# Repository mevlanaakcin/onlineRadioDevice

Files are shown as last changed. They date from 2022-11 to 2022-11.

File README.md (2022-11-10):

# onlineRadioStreamDevice
Bir IoT projesi olarak internet tabanlı radio yayın akışı oynatma projesi<br>
<h3>PCB Tasarımı</h3><br>
Elektronik devre şeması ve PCB board tasarımı Eagle de tasarlandı.<br>


<h3>Masaüstü Uygulama</h3><br>
C# ile masaüstü uygulaması sayesinde cihazın set ayarları yapılabiliyor. Wifi bilgileri set edilebiliyor. Yayın akışı takip edilecek link bilgileri set edilebiliyor. Cihaza isim atanabiliyor. Tüm bu işlemler masaüstü uygulaması ile cihaz arasında serial haberleşme ile yapılıyor. Cihaza daha önceden set edilen bilgiler çekilebiliyor.<br>

<h3>Gömülü Yazılım</h3><br>
ESP8266 kullanarak Wifi desteğinden faydalanarak gömülü yazılımı geliştirdim.<br>
EEPROM hafıza kullanıldı.<br>
Serial Haberleşme kullanıldı.<br>
WPS Bağlantı kullanıldı.<br>
I2S kullanıldı.<br>

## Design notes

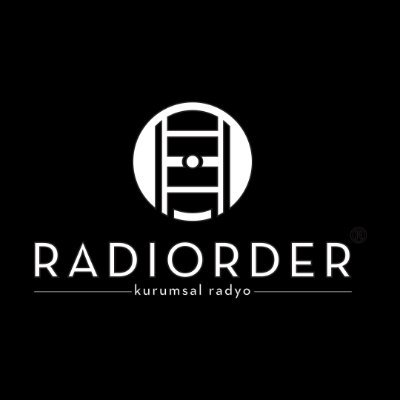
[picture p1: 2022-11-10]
Masaüstü Uygulama/Resources/q3KudRJM.jpg

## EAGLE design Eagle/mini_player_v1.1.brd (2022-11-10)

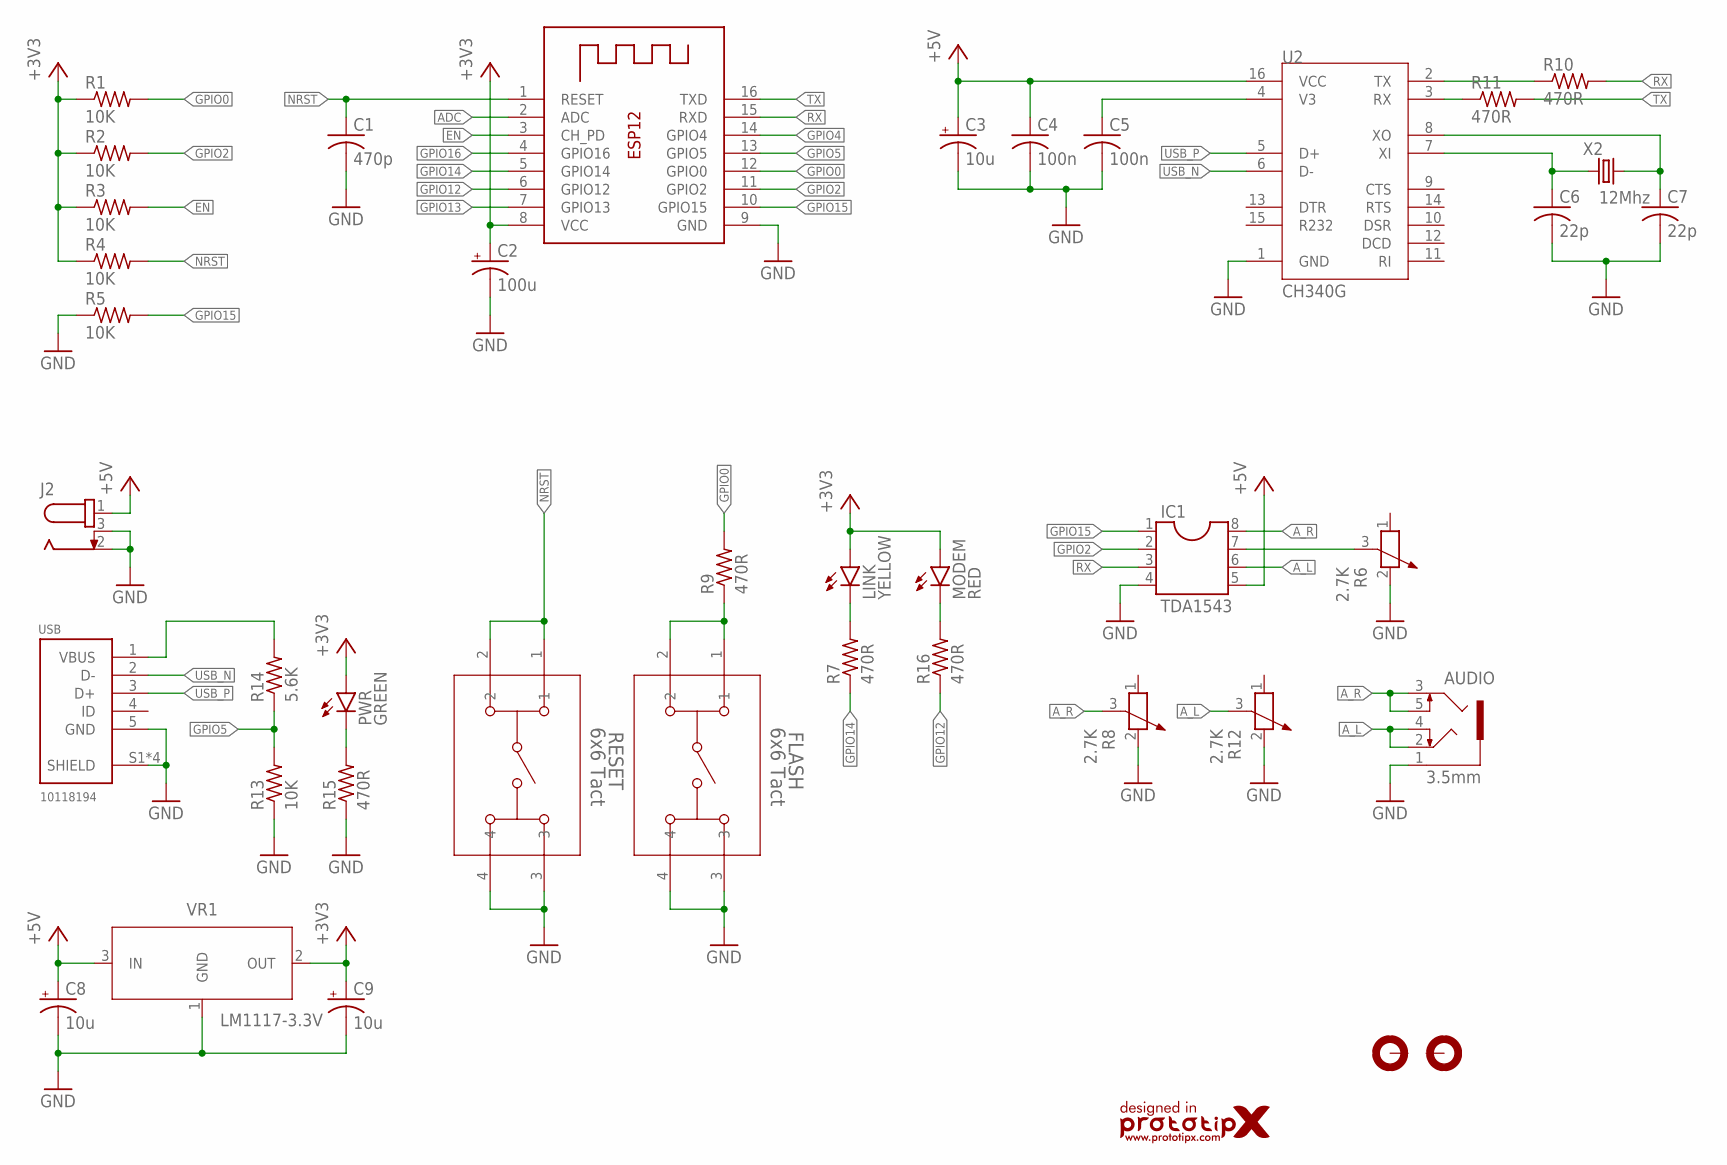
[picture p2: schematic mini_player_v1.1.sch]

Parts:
AUDIO: 3.5mm; 1503_09
C1: 470p; C0805
C2: 100u; SMC_B
C3, C8, C9: 10u; SMC_B
C4, C5: 100n; C0805
C6, C7: 22p; C0805
FLASH: 6x6 Tact; SW4_1825910-G
H1, H2: MOUNT-PAD-ROUND3.6; 3,6-PAD
IC1: TDA1543; DIL08
J2: 694106301002
LINK: YELLOW; LED3MM
LOGO1: PROTOTIPXDESIGN2; PROTOTIPX_DESING_15MM
MODEM: RED; LED3MM
PWR: GREEN; LED3MM
R1, R2, R3, R4, R5, R13: 10K; R0805
R6, R8, R12: 2.7K; PT-10
R7, R9, R10, R11, R15, R16: 470R; R0805
R14: 5.6K; R0805
RESET: 6x6 Tact; SW4_1825910-G
U1: ESP12E; ESP-12
U2: CH340G; SOIC16
USB: 10118194
VR1: LM1117-3.3V; SOT230P700X170-4
X2: 12Mhz; 5032/2P

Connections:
+3V3: C2.+, C9.+, LINK.A, MODEM.A, PWR.A, R1.1, R2.1, R3.1, R4.1, U1.8 (VCC), VR1.2 (OUT)
+5V: C3.+, C4.1, C8.+, IC1.5, J2.1, U2.16 (VCC), VR1.3 (IN)
ADC: U1.2 (ADC)
A_L: AUDIO.2, AUDIO.4, IC1.6, R12.3
A_R: AUDIO.3, AUDIO.5, IC1.8, R8.3
EN: R3.2, U1.3 (CH_PD)
GND: AUDIO.1, C1.2, C2.-, C3.-, C4.2, C5.2, C6.2, C7.2, C8.-, C9.-, FLASH.3, FLASH.4, IC1.4, J2.2, J2.3, R5.1, R6.2, R8.2, R12.2, R13.1, R15.1, RESET.3, RESET.4, U1.9 (GND), U2.1 (GND), USB.5 (GND), USB.S1 (SHIELD), USB.S2 (SHIELD), USB.S3 (SHIELD), USB.S6 (SHIELD), VR1.1 (GND)
GPIO0: R1.2, R9.2, U1.12 (GPIO0)
GPIO2: IC1.2, R2.2, U1.11 (GPIO2)
GPIO4: U1.14 (GPIO4)
GPIO5: R13.2, R14.1, U1.13 (GPIO5)
GPIO12: R16.1, U1.6 (GPIO12)
GPIO13: U1.7 (GPIO13)
GPIO14: R7.1, U1.5 (GPIO14)
GPIO15: IC1.1, R5.2, U1.10 (GPIO15)
GPIO16: U1.4 (GPIO16)
unnamed: R14.2, USB.1 (VBUS)
unnamed: FLASH.1, FLASH.2, R9.1
unnamed: C5.1, U2.4 (V3)
unnamed: C6.1, U2.7 (XI), X2.1
unnamed: C7.1, U2.8 (XO), X2.2
unnamed: R11.1, U2.3 (RX)
unnamed: R10.1, U2.2 (TX)
unnamed: MODEM.K (C), R16.2
unnamed: PWR.K (C), R15.2
unnamed: LINK.K (C), R7.2
NRST: C1.1, R4.2, RESET.1, RESET.2, U1.1 (RESET)
RX: IC1.3, R10.2, U1.15 (RXD)
TX: R11.2, U1.16 (TXD)
USB_N: U2.6 (D-), USB.2 (D-)
USB_P: U2.5 (D+), USB.3 (D+)
VREF: IC1.7, R6.3

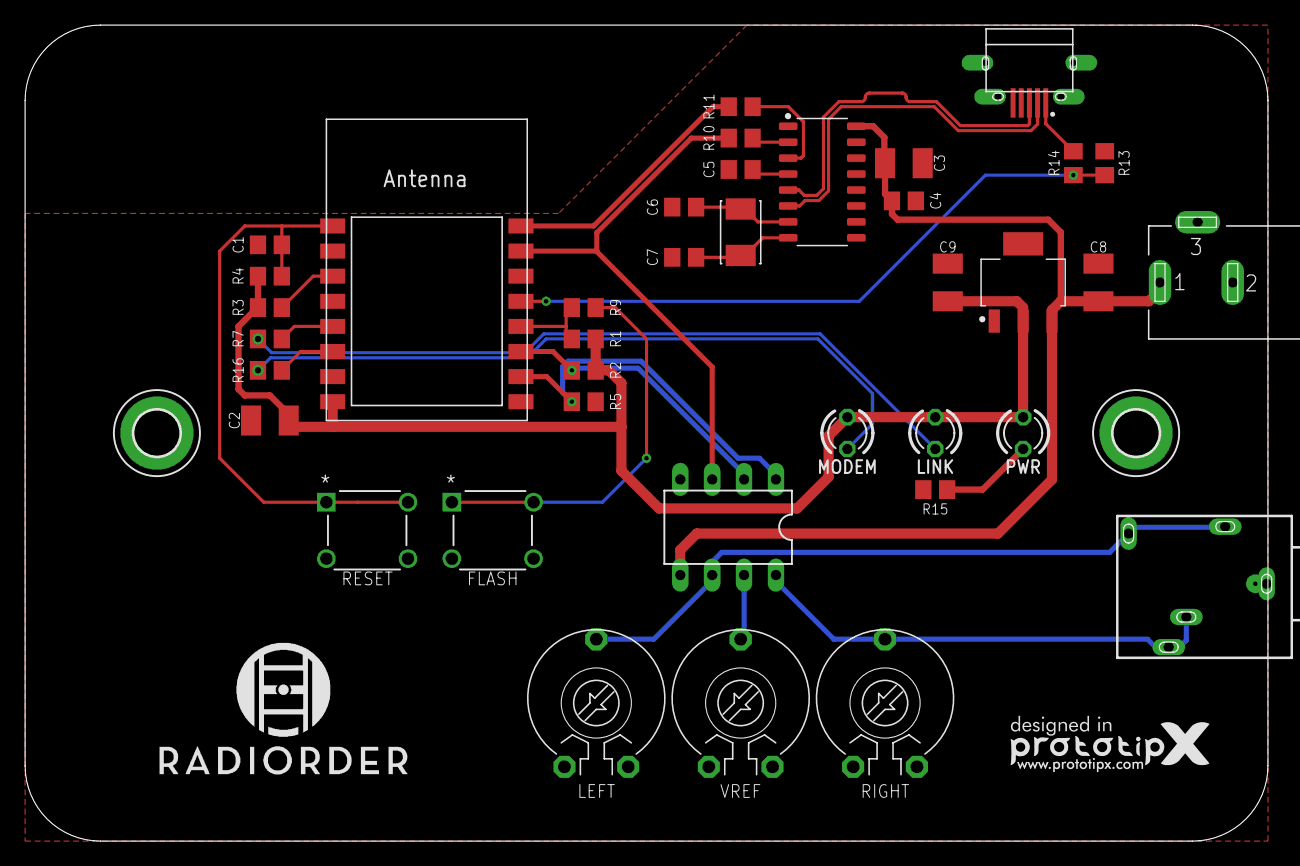
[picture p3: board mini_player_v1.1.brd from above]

Board: 2 copper layers, 99.0 x 65.0 mm, 41 parts (0 on the bottom side), 28 nets.

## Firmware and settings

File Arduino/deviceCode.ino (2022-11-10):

#include <Arduino.h>
#ifdef ESP32
#include <WiFi.h>
#else
#include <ESP8266WiFi.h>
#endif
#include"EEPROM.h"
#include<String.h>
#include "AudioFileSourceICYStream.h"
#include "AudioFileSourceBuffer.h"
#include "AudioGeneratorMP3.h"
#include "AudioOutputI2S.h"
#include "WPS.h"

#define button 5
#define serialButon 4
#define led 12
#define linkled 14
WPS wps(button, led);

char ssid[50];
char password[50];
char URL[100] ;
String WiFidata;
String eepromSsid;
String eepromPass;
String eepromLink;
boolean serial = false;

String okunan = "";
AudioGeneratorMP3 *mp3;
AudioFileSourceICYStream *file;
AudioFileSourceBuffer *buff;
AudioOutputI2S *out;

// Called when a metadata event occurs (i.e. an ID3 tag, an ICY block, etc.
void MDCallback(void *cbData, const char *type, bool isUnicode, const char *string)
{
  const char *ptr = reinterpret_cast<const char *>(cbData);
  (void) isUnicode; // Punt this ball for now
  // Note that the type and string may be in PROGMEM, so copy them to RAM for printf
  char s1[32], s2[64];
  strncpy_P(s1, type, sizeof(s1));
  s1[sizeof(s1) - 1] = 0;
  strncpy_P(s2, string, sizeof(s2));
  s2[sizeof(s2) - 1] = 0;
  //Serial.printf("METADATA(%s) '%s' = '%s'\n", ptr, s1, s2);
  //Serial.flush();
}

// Called when there's a warning or error (like a buffer underflow or decode hiccup)
void StatusCallback(void *cbData, int code, const char *string)
{
  const char *ptr = reinterpret_cast<const char *>(cbData);
  // Note that the string may be in PROGMEM, so copy it to RAM for printf
  char s1[64];
  strncpy_P(s1, string, sizeof(s1));
  s1[sizeof(s1) - 1] = 0;
  //Serial.printf("STATUS(%s) '%d' = '%s'\n", ptr, code, s1);
  //Serial.flush();
}

String readwifidata() {
  String wifiinfo = "";
  for (int i = 0; i < 128; i++) {
    char oku = EEPROM.read(i);
    wifiinfo += oku;
  }
  EEPROM.commit();
  return wifiinfo;
}
String readnamedata() {
  String namedata = "";
  for (int i = 128; i < 256; i++) {
    char d = EEPROM.read(i);

    namedata += d;
  }
  EEPROM.commit();
  return namedata;

}
String readlinkdata() {
  String linkdata = "";
  for (int i = 256; i < 512; i++) {
    char d = EEPROM.read(i);

    linkdata += d;
  }
  EEPROM.commit();
  return linkdata;
}


void clearwifi() {
  for (int i = 0; i < 128; i++) {
    EEPROM.write(i, 0);
  }
  EEPROM.commit();
}
void clearname() {
  for (int i = 128; i < 256; i++) {
    EEPROM.write(i, 0);
  }
  EEPROM.commit();

}
void clearlink() {
  for (int i = 256; i < 512; i++) {
    EEPROM.write(i, 0);
  }
  EEPROM.commit();
}

void setup() {
  Serial.begin(115200);
  EEPROM.begin(512);

  pinMode(serialButon, INPUT);
  pinMode(linkled, OUTPUT);
  digitalWrite(linkled, LOW);

  int butonDeger = digitalRead(serialButon);
  delay(80);
  if (butonDeger == HIGH) {
    serial = true;
  } else {
    serial = false;
  }

  while (serial) { // serial=true iletişim var ise while döngüsüne gir masaüstü ile iletişim kuruluyor

    if (Serial.available() > 0) {
      okunan = Serial.readStringUntil('\n');

      if (okunan[0] == '#') {
        for (int i = 0; i < okunan.length(); i++) {
          EEPROM.write(i, okunan[i]);
        }
        okunan = "";
      }
      else if (okunan[0] == '%') {
        String c = readwifidata();
        int t = c.length();
        int uzunluk = t + okunan.length();
        int j = 0;
        for (t; t < uzunluk; t++) {
          EEPROM.write(t, okunan[j]); 
          j++;
        }
        okunan = "";

      }
      else if (okunan[0] == '*') {
        String a = readwifidata();
        String b = readnamedata();
        int s = a.length() + b.length();
        int uzunluk = s + okunan.length();
        int j = 0;
        for (s; s < uzunluk; s++) {
          EEPROM.write(s, okunan[j]);
          j++;
        }
        okunan = "";
      }

      else  if (okunan[0] == '1') {
        Serial.println(readwifidata());
      }
      else if (okunan[0] == '2') {
        Serial.println(readnamedata());
      }
      else  if (okunan[0] == '3') {
        Serial.println(readlinkdata());
      }
      else if (okunan[0] == '4') {
        clearwifi();
      }
      else if (okunan[0] == '5') {
        clearname();
      }
      else if (okunan[0] == '6') {
        clearlink();
      }
      else if (okunan[0] == 'W') {
        serial = false;
      }
      else {
        okunan = "";
      }

    }
  }
  //**************************************************************************************

  WiFidata = readwifidata();
  if (WiFidata[0] != '#') { // bu ife girerse WPS bağlantı yapacaktır
   //Serial.println("WPS bağlantı gerçekleşicektir");
   // Serial.println(readnamedata());
    WiFi.mode(WIFI_STA);
    WiFi.begin("", "");
    wps.handleClient();
  }
  else {
    //Serial.println("SSID ve PASSWORD ile bağlantı gerçekleşicektir");
    int cont = 0;
    for (int i = 0; i < WiFidata.length(); i++) {
      if (WiFidata[i] == '#' ) {
        cont = 1;
      }
      if (WiFidata[i] == ':') {
        cont = 2;
      }
      if (WiFidata[i] != '#' && cont == 1) {
        eepromSsid += WiFidata[i];
      }
      if (WiFidata[i] != ':' && cont == 2) {
        eepromPass += WiFidata[i];
      }

    }
    // String char dönüşümü yaptık
    eepromSsid.toCharArray(ssid, 50);
    eepromPass.toCharArray(password, 50);


    WiFi.disconnect();
    WiFi.softAPdisconnect(true);
    WiFi.mode(WIFI_STA);
    //Serial.print("SSID: "); Serial.println(ssid);
    //Serial.print("PASSWORD: "); Serial.println(password);
    WiFi.begin(ssid, password);

    // Try forever
    while (WiFi.status() != WL_CONNECTED) {
      //Serial.println("...Connecting to WiFi");
      digitalWrite(led, 1);
      delay(500);
      digitalWrite(led, 0);
      delay(500);
    }

  }

  //eepromLink de linkin başındaki * a bakıyoruz
  eepromLink = readlinkdata();
  String a;
  for (int i = 1; i < eepromLink.length(); i++) {
    a += eepromLink[i];
  }
  a.toCharArray(URL, 100);

  //Ekrana çıktılar alıyorum

  //Serial.print("LINK: "); Serial.println(URL);


  audioLogger = &Serial;
  file = new AudioFileSourceICYStream(URL);
  file->RegisterMetadataCB(MDCallback, (void*)"ICY");
  buff = new AudioFileSourceBuffer(file, 8192);
  buff->RegisterStatusCB(StatusCallback, (void*)"buffer");
  out = new AudioOutputI2S();
  mp3 = new AudioGeneratorMP3();
  mp3->RegisterStatusCB(StatusCallback, (void*)"mp3");
  mp3->begin(buff, out);


}
void(* resetFunc) (void) = 0; //declare reset function @ address 0

void loop() {



  static int lastms = 0;

  if (mp3->isRunning()) { //müzik çalıyor ise
    if (millis() - lastms > 1000) {
      lastms = millis();
      //Serial.printf("Running for %d ms...\n", lastms);
      //Serial.flush();
    }
    if (!mp3->loop()) mp3->stop();
  }
  else { // müzik çalmıyor ise
    //Serial.printf("MP3 done\n");
    delay(1000);

    if (WiFi.status() != WL_CONNECTED) {
      wps.handleClient();
      audioLogger = &Serial;
      file = new AudioFileSourceICYStream(URL);
      file->RegisterMetadataCB(MDCallback, (void*)"ICY");
      buff = new AudioFileSourceBuffer(file, 8192);
      buff->RegisterStatusCB(StatusCallback, (void*)"buffer");
      out = new AudioOutputI2S();
      mp3 = new AudioGeneratorMP3();
      mp3->RegisterStatusCB(StatusCallback, (void*)"mp3");
      mp3->begin(buff, out);
    }
    if (URL[0] != 'h') {
      digitalWrite(linkled, HIGH);
    }

    else {
      digitalWrite(linkled, LOW);
      resetFunc();
    }
  }
}

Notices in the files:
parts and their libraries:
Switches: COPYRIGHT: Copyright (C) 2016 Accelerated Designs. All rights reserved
